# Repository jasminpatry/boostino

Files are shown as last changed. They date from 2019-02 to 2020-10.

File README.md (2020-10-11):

# BooSTIno
A Teensy 3.6-based logger and gauge for my 2014 Subaru STI.

Photo of current version:

BooSTIno (https://ibb.co/G0bdSqY)

Short [YouTube video](https://www.youtube.com/watch?v=nscQxxUsuL8) of older version, without faceplate or wideband support:

YouTube (https://www.youtube.com/watch?v=nscQxxUsuL8)

See [this thread on NASIOC](https://forums.nasioc.com/forums/showthread.php?t=2896098) for more info.

# Compilation

This project is built as an Arduino sketch. I used Arduino 1.8.8, but later versions will likely work too. You will also need the Teensyduino add-on
(https://www.pjrc.com/teensy/td_download.html), and the following libraries:

* My fork of ILI9341_t3: https://github.com/jasminpatry/ILI9341_t3
* My fork of Adafruit_GFX: https://github.com/jasminpatry/Adafruit-GFX-Library
* font_Exo-BoldItalic: https://github.com/FrankBoesing/fonts/tree/master/ofl/exo

# Hardware

This project was built using the following hardware:

* [Teensy 3.6](https://www.pjrc.com/store/teensy36.html)
* MC33660 K-line serial interface chip, SOP-8 package ([datasheet](https://www.nxp.com/docs/en/data-sheet/MC33660.pdf)); I purchased mine from [eBay](https://www.ebay.com/itm/10PCS-MC33660-MC33660EF-SOP-8/292559702234)
* Custom PCB fabricated using the files in the [KiCad/boostino.gerber](KiCad/boostino.gerber) directory (I used [BasicPCB](https://www.basicpcb.com/)'s ValueSpec option, which in 2020 cost me about $30 for 3 boards).
* [HiLetgo ILI9341 2.8" SPI TFT LCD Display Touch Panel 240X320 with PCB 5V/3.3V STM32](https://www.amazon.com/gp/product/B073R7BH1B/)
* [OBD-2 cable](https://www.amazon.com/gp/product/B01ETRINYO/) &mdash; the switch and DB9 connector in the linked cable aren't necessary (I snipped them off), but the DB9 connector was useful when prototyping.
* [Innovate Motorsports (3877) LC-2 Digital Wideband Lambda Controller Kit with Bosch LSU 4.9 O2 Sensor](https://www.amazon.com/Innovate-Motorsports-Digital-Wideband-Controller/dp/B00FFTAJPC/) (optional; only necessary for AFR display and logging)
* [Molex Micro-Fit 3.0 plug](https://www.amazon.com/gp/product/B078Q798L9/) for connecting to the LC-2 serial output (optional; only necessary for AFR display and logging)
* [Elcoho 10 Pieces Plastic Waterproof Boxes Junction Case Compatible with Electronic Project 3.94 × 2.36 × 0.98 Inches, Black](https://www.amazon.com/gp/product/B07G8S6XLV/)
* For the faceplate, I had [faceplate.eps](faceplate.eps) laser-cut by https://www.ponoko.com/ using:
    * Acrylic - Two Color - Brushed Silver on Black
    * 0.059 inches thick
    * P1 - 7.126 inches long x 7.126 inches wide
* Miscellaneous cables, headers, resistors, capacitors, diodes, wires, screws & nuts, etc.

# Tactrix Version

A previous version of this project used the [Tactrix OpenPort 2.0](https://www.tactrix.com/index.php?product_id=17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) to communicate with the ECU. That version is available in the [Tactrix](../../tree/Tactrix/) branch.

# Donate

If this project proves useful to you, please consider making a donation!



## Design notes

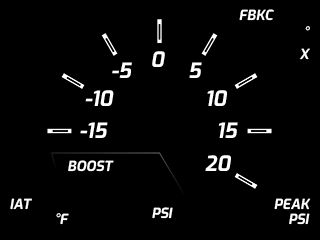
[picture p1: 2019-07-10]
gaugeFg.png

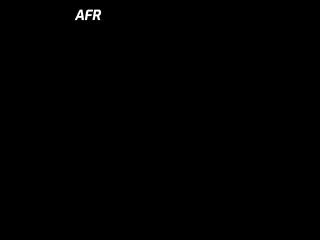
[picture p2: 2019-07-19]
labelAfr.png

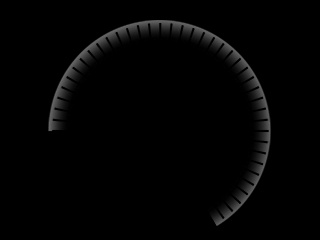
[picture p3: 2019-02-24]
gaugeBg.png

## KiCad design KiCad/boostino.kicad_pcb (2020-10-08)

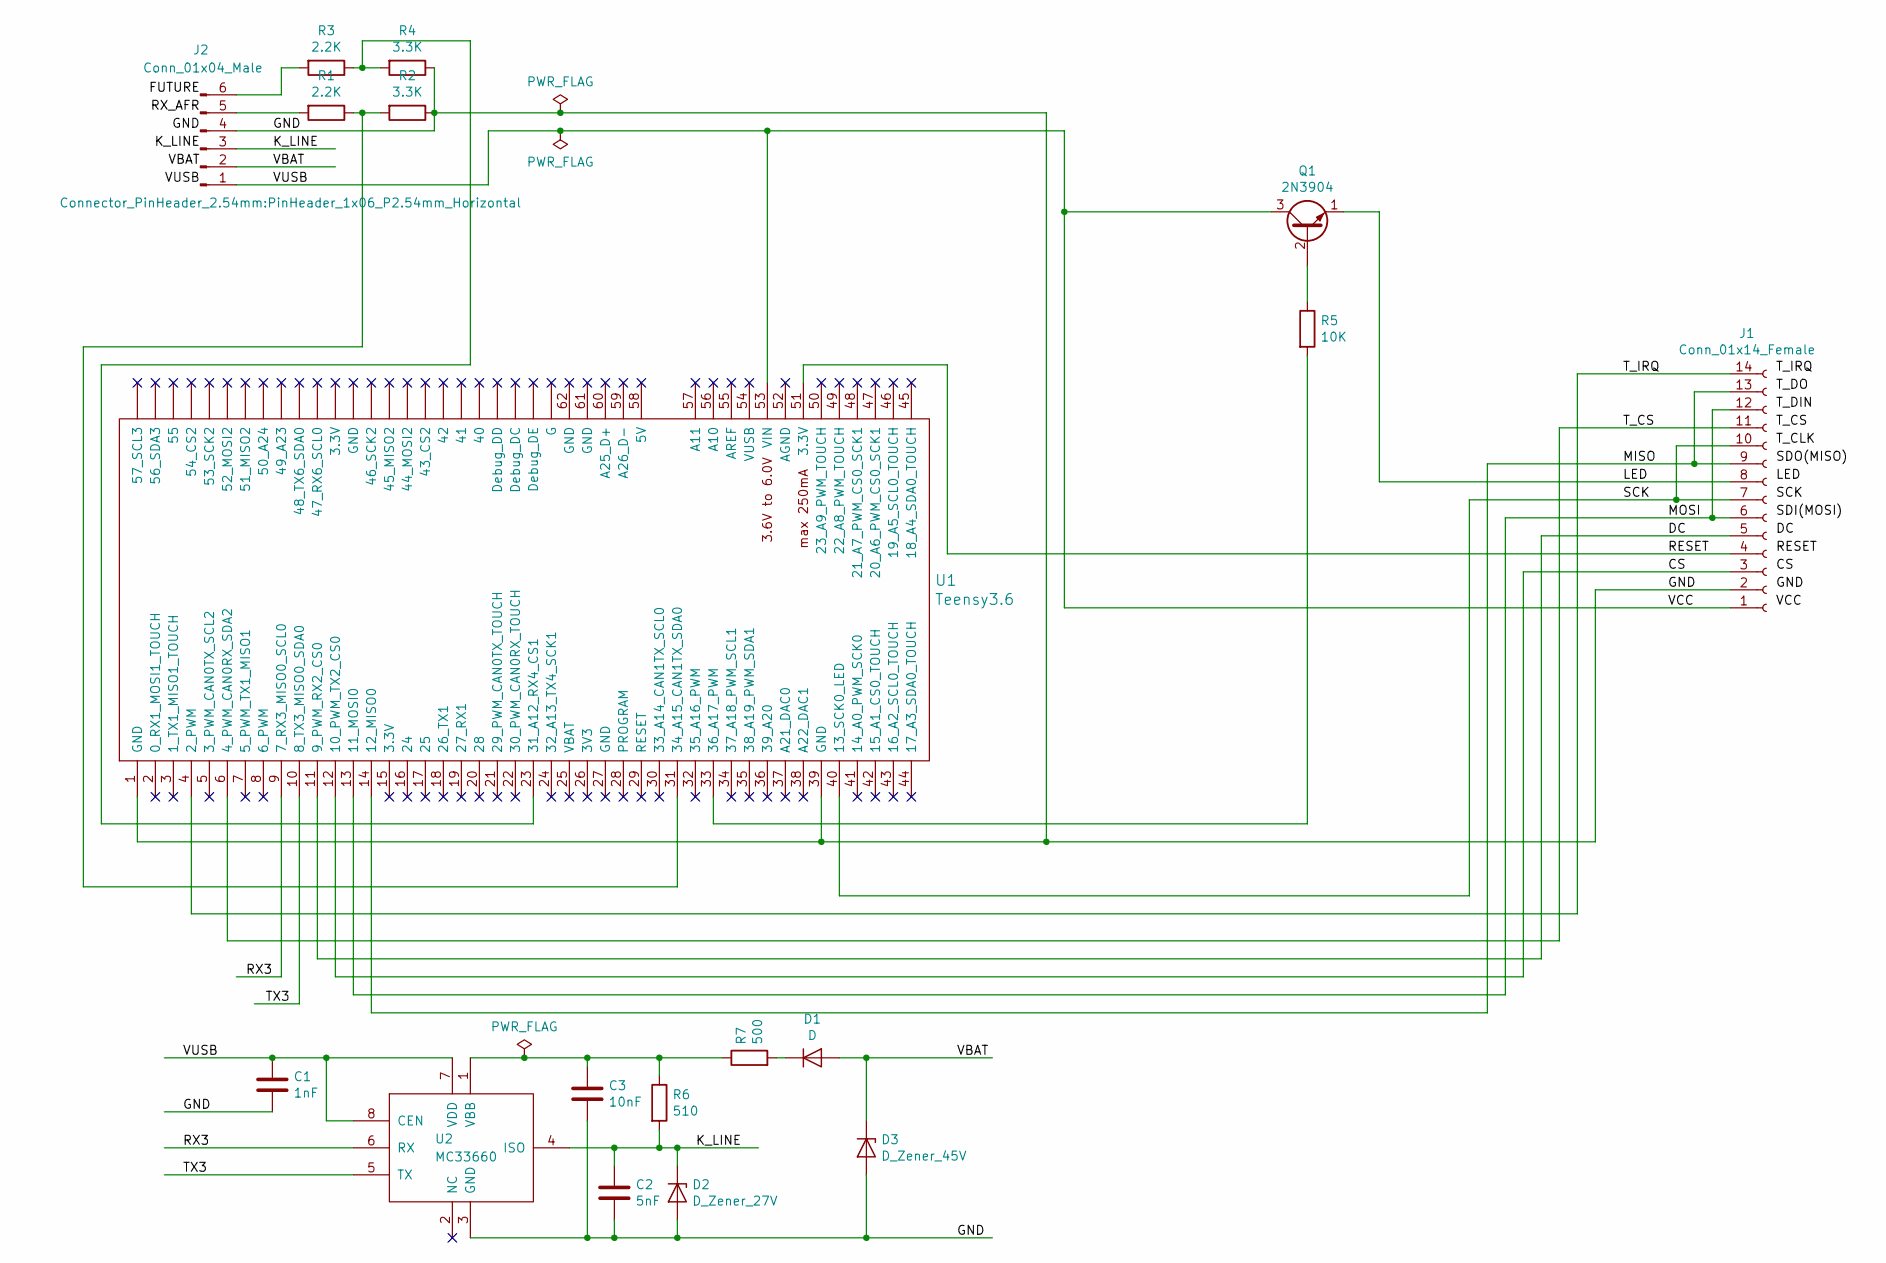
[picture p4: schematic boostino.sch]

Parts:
C1: 1nF; C_1206_3216Metric_Pad1.42x1.75mm_HandSolder
C2: 5nF; C_1206_3216Metric_Pad1.42x1.75mm_HandSolder
C3: 10nF; C_1206_3216Metric_Pad1.42x1.75mm_HandSolder
D1: D; D_A-405_P10.16mm_Horizontal
D2: D_Zener_27V; D_MiniMELF_Handsoldering
D3: D_Zener_45V; D_MiniMELF_Handsoldering
J1: Conn_01x14_Female; PinSocket_1x14_P2.54mm_Vertical
J2: Conn_01x04_Male; PinHeader_1x06_P2.54mm_Horizontal
Q1: 2N3904; TO-92_HandSolder
R1, R3: 2.2K; R_0805_2012Metric_Pad1.15x1.40mm_HandSolder
R2, R4: 3.3K; R_0805_2012Metric_Pad1.15x1.40mm_HandSolder
R5: 10K; R_0805_2012Metric_Pad1.15x1.40mm_HandSolder
R6: 510; R_0805_2012Metric_Pad1.15x1.40mm_HandSolder
R7: 500; R_0805_2012Metric_Pad1.15x1.40mm_HandSolder
U1: Teensy3.6; Teensy35_36
U2: MC33660; SOIC-8_3.9x4.9mm_P1.27mm

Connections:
/CS: J1.3, U1.12 (10_PWM_TX2_CS0)
/DC: J1.5, U1.11 (9_PWM_RX2_CS0)
/GND: C1.1, C2.1, C3.1, D2.2 (A), D3.2 (A), J1.2, J2.4, R2.1, R4.1, U1.1 (GND), U1.39 (GND), U2.3 (GND)
/K_LINE: C2.2, D2.1 (K), J2.3, R6.2, U2.4 (ISO)
/LED: J1.8, Q1.1 (E)
/MISO: J1.9, J1.13, U1.14 (12_MISO0)
/MOSI: J1.6, J1.12, U1.13 (11_MOSI0)
/RESET: J1.4, U1.51 (3.3V)
/RX3: U1.9 (7_RX3_MISO0_SCL0), U2.6 (RX)
/SCK: J1.7, J1.10, U1.40 (13_SCK0_LED)
/TX3: U1.10 (8_TX3_MISO0_SDA0), U2.5 (TX)
/T_CS: J1.11, U1.6 (4_PWM_CAN0RX_SDA2)
/T_IRQ: J1.14, U1.4 (2_PWM)
/VBAT: D1.2 (A), D3.1 (K), J2.2
/VCC: C1.2, J1.1, J2.1, Q1.3 (C), U1.53 (VIN), U2.7 (VDD), U2.8 (CEN)
unnamed: C3.2, R6.1, R7.1, U2.1 (VBB)
unnamed: D1.1 (K), R7.2
unnamed: J2.5, R1.2
unnamed: J2.6, R3.2
unnamed: Q1.2 (B), R5.1
unnamed: R1.1, R2.2, U1.31 (34_A15_CAN1TX_SDA0)
unnamed: R3.1, R4.2, U1.23 (31_A12_RX4_CS1)
unnamed: R5.2, U1.33 (36_A17_PWM)

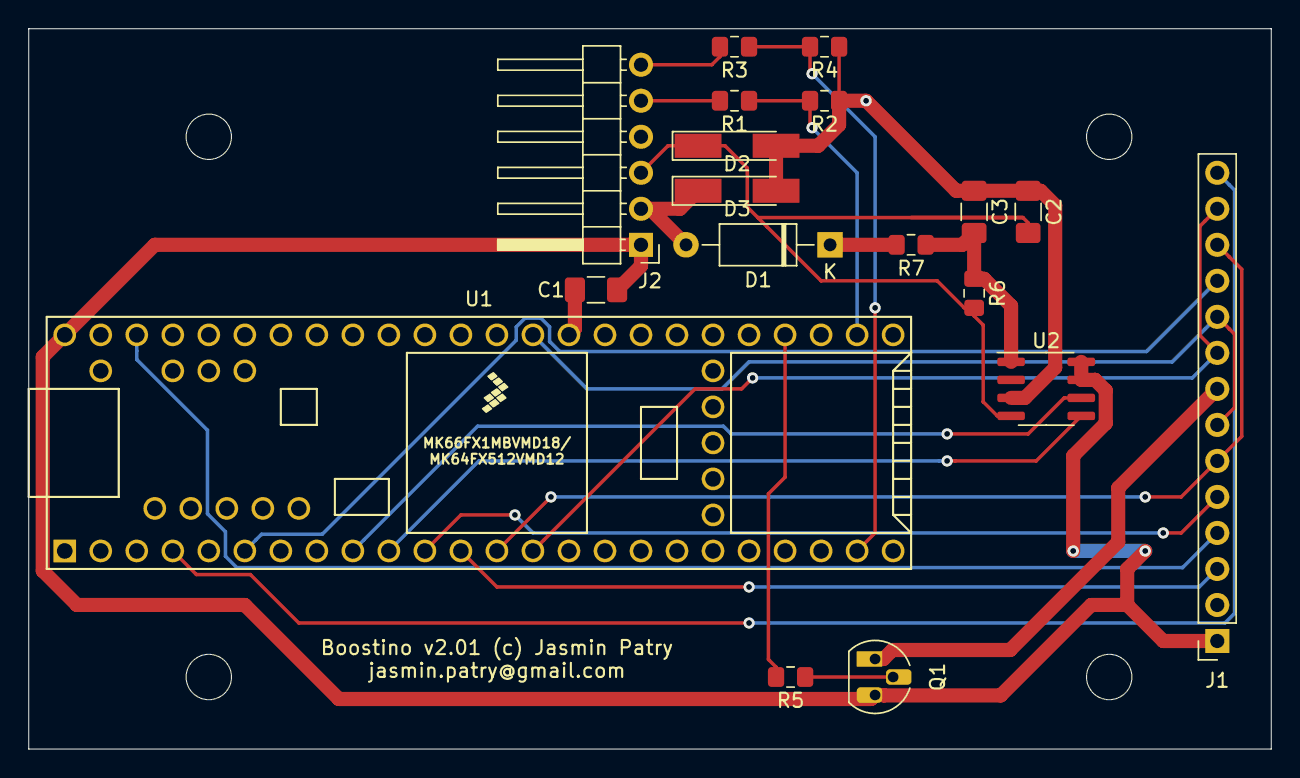
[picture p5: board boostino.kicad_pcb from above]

Board: 2 copper layers, 87.6 x 50.8 mm, 18 parts (0 on the bottom side), 23 nets.

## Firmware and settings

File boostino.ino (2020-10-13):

// Boostino -- A Teensy 3.6 SSM logger and gauge.
// Copyright (c) 2019, 2020 Jasmin Patry
//
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
#include <Adafruit_GFX.h>
#include <EEPROM.h>
#include <font_Exo-BoldItalic.h>
#include <ILI9341_t3.h>
#include <SD.h>
#include <XPT2046_Touchscreen.h>

#include "gaugeBg.h"
#include "gaugeFg.h"
#include "labelMph.h"
#include "labelAfr.h"



// Set to 1 to enable verbose logging.

#define DEBUG 0

static const bool s_fTraceComms = false;
static const bool s_fTraceTouch = false;

// Set to 1 to test without being plugged into the vehicle

#define TEST_OFFLINE 0



// Useful macros, typedefs, etc.

#define CASSERT(f) static_assert(f, #f)

template <typename T, int N>
constexpr int DIM(T (&aT)[N])
{
	(void)aT;
	return N;
}

typedef uint32_t	u32;
typedef int32_t		s32;
typedef uint16_t	u16;
typedef int16_t		s16;
typedef uint8_t		u8;
typedef int8_t		s8;

CASSERT(sizeof(int) == 4);		// Teensy 3.6 is 32-bit
CASSERT(sizeof(void *) == 4);	//	...

static const float s_gPi = 3.14159265f;

#define KLINE Serial3



// Available ECU parameters

enum PARAM
{
	PARAM_FbkcDeg,
	PARAM_FlkcDeg,
	PARAM_AtmPres,
	PARAM_ManifAbsPres,
	PARAM_BoostPsi,		// NOTE (jpatry) Calculated from PARAM_ManifAbsPres and PARAM_AtmPres
	PARAM_Iam,
	PARAM_CoolantTempF,	// BB (jpatry) Currently unused
	PARAM_Rpm,
	PARAM_Maf,
	PARAM_LoadGPerRev,	// NOTE (jpatry) Calculated from PARAM_Rpm and PARAM_Maf
	PARAM_IatF,
	PARAM_ThrottlePct,
	PARAM_SpeedMph,
	PARAM_IpwMs,
	PARAM_IdcPct,		// NOTE (jpatry) Calculated from PARAM_Rpm and PARAM_IpwMs
	PARAM_Afr1,
	PARAM_WidebandAfr,	// Read from analog input
	PARAM_TargetAfr,
	PARAM_MafVoltage,
	PARAM_LightSwitch,	// BB (jpatry) Always 1 unless parking brake is up, so not useful.

	PARAM_Max,
	PARAM_Min = 0,
	PARAM_Nil
};

PARAM & operator++(PARAM & param)
{
	param = PARAM(param + 1);
	return param;
}

static const char * s_mpParamPChz[] =
{
	"Feedback Knock Correction (4-byte)* (degrees)",	// PARAM_FbkcDeg
	"Fine Learning Knock Correction (degrees)",			// PARAM_FlkcDeg
	"Atmospheric Pressure (psi)",						// PARAM_AtmPres
	"Manifold Absolute Pressure (psi)",					// PARAM_ManifAbsPres
	"Manifold Relative Pressure (psi)",					// PARAM_BoostPsi
	"IAM (multiplier)",									// PARAM_Iam
	"Coolant Temperature (F)",							// PARAM_CoolantTempF
	"Engine Speed (rpm)",								// PARAM_Rpm
	"Mass Airflow (g/s)",								// PARAM_Maf
	"Engine Load (Calculated) (g/rev)",					// PARAM_LoadGPerRev
	"Intake Air Temperature (F)",						// PARAM_IatF
	"Throttle Opening Angle (%)",						// PARAM_ThrottlePct
	"Vehicle Speed (mph)",								// PARAM_SpeedMph
	"Fuel Injector #1 Pulse Width",						// PARAM_IpwMs
	"Injector Duty Cycle",								// PARAM_IdcPct
	"A/F Sensor #1",									// PARAM_Afr1
	"Wideband A/F Sensor",								// PARAM_WidebandAfr
	"Final Fueling Base (2-byte)* (estimated AFR)",		// PARAM_TargetAfr
	"Mass Airflow Sensor Voltage (V)",					// PARAM_MafVoltage
	"Light Switch",										// PARAM_LightSwitch
};
CASSERT(DIM(s_mpParamPChz) == PARAM_Max);

static const u8 s_cBSsmAddr = 3;
static const u32 s_mpParamABAddr[] =
{
	0xff81fc,		// PARAM_FbkcDeg
	0x000199,		// PARAM_FlkcDeg
	0x000023,		// PARAM_AtmPres
	0x00000D,		// PARAM_ManifAbsPres
	0x000000,		// PARAM_BoostPsi
	0x0000f9,		// PARAM_Iam
	0x000008,		// PARAM_CoolantTempF
	0x00000e,		// PARAM_Rpm
	0x000013,		// PARAM_Maf
	0x000000,		// PARAM_LoadGPerRev
	0x000012,		// PARAM_IatF
	0x000015,		// PARAM_ThrottlePct
	0x000010,		// PARAM_SpeedMph
	0x000020,		// PARAM_IpwMs
	0x000000,		// PARAM_IdcPct
	0x000046,		// PARAM_Afr1
	0x000000,		// PARAM_WidebandAfr
	0xff688a,		// PARAM_TargetAfr
	0x00001d,		// PARAM_MafVoltage
	0x000064,		// PARAM_LightSwitch
};
CASSERT(DIM(s_mpParamABAddr) == PARAM_Max);

static const u8 s_mpParamCB[] =
{
	 4,		// PARAM_FbkcDeg
	 1,		// PARAM_FlkcDeg
	 1,		// PARAM_AtmPres
	 1,		// PARAM_ManifAbsPres
	 0,		// PARAM_BoostPsi
	 1,		// PARAM_Iam
	 1,		// PARAM_CoolantTempF
	 2,		// PARAM_Rpm
	 2,		// PARAM_Maf
	 0,		// PARAM_LoadGPerRev
	 1,		// PARAM_IatF
	 1,		// PARAM_ThrottlePct
	 1,		// PARAM_SpeedMph
	 1,		// PARAM_IpwMs
	 0,		// PARAM_IdcPct
	 1,		// PARAM_Afr1
	 0,		// PARAM_WidebandAfr
	 2,		// PARAM_TargetAfr
	 1,		// PARAM_MafVoltage
	 1,		// PARAM_LightSwitch
};
CASSERT(DIM(s_mpParamCB) == PARAM_Max);

// BB (jpatry) Learning Table value data, for future:
// { 0xff31d4, 4, "A/F Learning #1 A (Stored)*" }, // float, x*100, %
// { 0xff31dc, 4, "A/F Learning #1 B (Stored)*" }, // float, x*100, %
// { 0xff31e4, 4, "A/F Learning #1 C (Stored)*" }, // float, x*100, %
// { 0xff31ec, 4, "A/F Learning #1 D (Stored)*" }, // float, x*100, %
// { 0x0000d1, 1, "A/F Learning #3" }, // u8, (x-128)*100/128, %
// { 0x000023, 1, "Atmospheric Pressure" }, //u8,  x*37/255, psi
// { 0x00001c, 1, "Battery Voltage" }, // u8, x*8/100, V
// { 0x000008, 1, "Coolant Temperature" }, // u8, 32+9*(x-40)/5, F
// { 0xff8298, 4, "Fine Learning Knock Correction (4-byte)*" }, // float, x, degrees
// { 0xff329c, 4, "IAM (4-byte)*" }, // float, x, multiplier
// { 0x000012, 1, "Intake Air Temperature" }, // u8, 32+9*(x-40)/5, F
// { 0x0cce3c, 4, "A/F Learning #1 Airflow Ranges", 3 }, // float, x, g/s
// { 0x0d3dd8, 4 ,"Fine Correction Columns (Load)", 4 }, // float, x, g/rev
// { 0x0d3dbc, 4 ,"Fine Correction Rows (RPM)", 6 }, // float, x, RPM
// { 0xff32b0, 4 ,"Fine Correction Row 1 (degrees)", 5, 4 /*stride*/ }, // float, x, RPM // NOTE (jpatry) Address is IAM (4-byte) + 4
// { 0xff32d8, 4 ,"Fine Correction Row 2 (degrees)", 5, 4 /*stride*/ }, // float, x, RPM
// { 0xff3300, 4 ,"Fine Correction Row 3 (degrees)", 5, 4 /*stride*/ }, // float, x, RPM
// { 0xff3328, 4 ,"Fine Correction Row 4 (degrees)", 5, 4 /*stride*/ }, // float, x, RPM
// { 0xff3350, 4 ,"Fine Correction Row 5 (degrees)", 5, 4 /*stride*/ }, // float, x, RPM
// { 0xff3378, 4 ,"Fine Correction Row 6 (degrees)", 5, 4 /*stride*/ }, // float, x, RPM
// { 0xff33a0, 4 ,"Fine Correction Row 7 (degrees)", 5, 4 /*stride*/ }, // float, x, RPM



// ECU Parameters to Poll

static const PARAM s_aParamPoll[] =
{
	PARAM_FbkcDeg,		// 4 B
	PARAM_Rpm,			// 2 B
	PARAM_ManifAbsPres,	// 1 B
	PARAM_AtmPres,		// 1 B
	PARAM_Maf,			// 2 B
	PARAM_FlkcDeg,		// 1 B
	PARAM_Iam,			// 1 B
	PARAM_IatF,			// 1 B
	PARAM_ThrottlePct,	// 1 B
	PARAM_SpeedMph,		// 1 B
	PARAM_TargetAfr,	// 2 B
};
static const u8 s_cParamPoll = DIM(s_aParamPoll);



// ECU Parameters to Log

static const PARAM s_aParamLog[] =
{
	PARAM_LoadGPerRev,
	PARAM_Rpm,
	PARAM_Maf,
	PARAM_FbkcDeg,
	PARAM_FlkcDeg,
	PARAM_BoostPsi,
	PARAM_IatF,
	PARAM_ThrottlePct,
	PARAM_Iam,
	PARAM_WidebandAfr,
	PARAM_TargetAfr,
};
static const u8 s_cParamLog = DIM(s_aParamLog);



// Debugging support

inline void Trace(bool f, const char * pChz)
{
#if DEBUG
	if (f)
		Serial.print(pChz);
#endif // DEBUG
}

inline void Trace(bool f, u8 b, int mode = DEC)
{
#if DEBUG
	if (f)
		Serial.print(b, mode);
#endif // DEBUG
}

#if DEBUG
void Trace(bool f, char ch)
{
	if (!f)
		return;

	if (isprint(ch))
	{
		Serial.print(ch);
	}
	else
	{
		switch (ch)
		{
		case '\r':
			Serial.print("\\r");
			break;

		case '\n':
			Serial.print("\\n");
			break;

		case '\0':
			Serial.print("\\0");
			break;

		default:
			Serial.print("\\x");
			Serial.print(u8(ch), HEX);
			break;
		}
	}
}
#else // !DEBUG
inline void Trace(bool f, char ch)
{
}
#endif // !DEBUG

inline void Trace(bool f, u16 uN, int mode = DEC)
{
#if DEBUG
	if (f)
		Serial.print(uN, mode);
#endif // DEBUG
}

inline void Trace(bool f, s16 n, int mode = DEC)
{
#if DEBUG
	if (f)
		Serial.print(n, mode);
#endif // DEBUG
}

inline void Trace(bool f, u32 uN, int mode = DEC)
{
#if DEBUG
	if (f)
		Serial.print(uN, mode);
#endif // DEBUG
}

inline void Trace(bool f, int n, int mode = DEC)
{
#if DEBUG
	if (f)
		Serial.print(n, mode);
#endif // DEBUG
}

inline void Trace(bool f, float g, int cDigit = 2)
{
#if DEBUG
	if (f)
		Serial.print(g, cDigit);
#endif // DEBUG
}

#if DEBUG
void TraceHex(bool f, u8 b)
{
	if (!f)
		return;

	if (b < 0x10)
		Trace(true, '0');

	Trace(true, b, HEX);
}
#else // !DEBUG
inline void TraceHex(bool f, u8 b)
{
}
#endif // !DEBUG

#if DEBUG
void TraceHex(bool f, const u8 * aB, u16 cB)
{
	if (!f || cB == 0)
		return;

	int iB = 0;
	for (;;)
	{
		u8 b = aB[iB];
		TraceHex(true, b);

		++iB;
		if (iB >= cB)
			break;

		Trace(true, ' ');

		if (!(iB & 0xf))
			Trace(true, "\n");
		else if (!(iB & 0x3))
			Trace(true, "| ");
	}
	Trace(true, "\n");
}
#else // !DEBUG
inline void TraceHex(bool f, const u8 * aB, u16 cB)
{
}
#endif // !DEBUG



// BB (jpatry) Assigning __LINE__ to nAssertLine is necessary to get rid of warning about 'large integer implicitly
//	truncated to unsigned type'.

#define ASSERT(f)								\
	do											\
	{											\
		if (!(f))								\
		{										\
			Trace(true, "Assert failed (");		\
			Trace(true, __FILE__);				\
			Trace(true, ":");					\
			u32 nAssertLine = __LINE__;			\
			Trace(true, nAssertLine);			\
			Trace(true, "): ");					\
			Trace(true, #f);					\
			Trace(true, "\n");					\
		}										\
	} while(0)



// Subaru Select Monitor (SSM) protocol description: http://www.romraider.com/RomRaider/SsmProtocol
// Max SSM packet size is ~250 bytes

static const u8 s_cBSsmMax = 250;



// SSM Source/Destination IDs (ISO9141)

enum SSMID : u8
{
	SSMID_Ecu	  = 0x10,
	SSMID_TcuDccd = 0x18,
	SSMID_Tool	  = 0xf0,
};



// SSM Command/Response IDs

enum SSMCMD : u8
{
	SSMCMD_BlockReadRequest		= 0xa0,
	SSMCMD_AddressReadRequest	= 0xa8,
	SSMCMD_AddressReadResponse	= 0xe8,
	SSMCMD_WriteBlockRequest	= 0xb0,
	SSMCMD_AddressWriteRequest	= 0xb8,
	SSMCMD_EcuInitRequest		= 0xbf,
	SSMCMD_EcuInitResponse		= 0xff,
};



u8 BSsmChecksum(const u8 * aB, u16 cB)
{
	u8 bSum = 0;
	for (int iB = 0; iB < cB; ++iB)
		bSum += aB[iB];

	return bSum;
}



static const u8 s_bSsmHdr = 0x80;



// SSM Packet

struct SSsm	// tag = ssm
{
	u8		m_bHdr;				// 0x80
	SSMID	m_bDst;				// Destination
	SSMID	m_bSrc;				// Source
	u8		m_cB;				// Data + checksum size
	SSMCMD	m_bCmd;				// Command/response byte
	u8		m_aB[0];			// Data (including checksum as last byte)

	u8			CBPacket() const
					{ return sizeof(*this) + m_cB; }

	u8			CBData() const
					{ return m_cB - 1; }

	const u8 *	PBData() const
					{ return m_aB; }

	u8 *		PBChecksum()
					{ return &m_aB[CBData()]; }

	u8			BChecksum() const
					{ return m_aB[CBData()]; }

	u8			BComputeChecksum() const;
	bool		FVerifyChecksum() const;
};

u8 SSsm::BComputeChecksum() const
{
	const u8 * aB = (const u8 *)this;
	int cB = CBPacket() - 1;
	return BSsmChecksum(aB, cB);
}

bool SSsm::FVerifyChecksum() const
{
	u8 bChecksum = BComputeChecksum();
	if (bChecksum == BChecksum())
	{
		return true;
	}
	else
	{
		Trace(true, "SSM checksum error\n");
		return false;
	}
}



// Log entry

struct SLogEntry	// tag = logent
{
	u32		m_msTimestamp;
	float	m_mpIParamLogGValue[s_cParamLog];
};

// Number of entries in log history

static const int s_cEntryLogHistory = 32;

// Circular buffer of data to log, with capacity s_cEntryLogHistory

class CLogHistory
{
public:
	u8					CEntry() const
							{ return m_iaGWrite - m_iaGRead; }
	bool				FIsEmpty() const
							{ return m_iaGRead == m_iaGWrite; }
	bool				FIsFull() const
							{ return CEntry() == s_cEntryLogHistory; }
	const SLogEntry &	LogentRead();
	void				WriteLogEntry(const SLogEntry & logent);

protected:
	// Implementation based on https://www.snellman.net/blog/archive/2016-12-13-ring-buffers/

	CASSERT(s_cEntryLogHistory <= u8(~0));
	CASSERT((s_cEntryLogHistory & (s_cEntryLogHistory - 1)) == 0);

	u8				IMask(u8 i)
						{ return i & (s_cEntryLogHistory - 1); }

	SLogEntry		m_aLogent[s_cEntryLogHistory];
	u8				m_iaGRead;						// unmasked read index
	u8				m_iaGWrite;						// unmasked write index
};

const SLogEntry & CLogHistory::LogentRead()
{
	ASSERT(!FIsEmpty());
	return m_aLogent[IMask(m_iaGRead++)];
}

void CLogHistory::WriteLogEntry(const SLogEntry & logent)
{
	// Allow writing to full buffer by discarding oldest entry

	if (FIsFull())
		(void) LogentRead();

	m_aLogent[IMask(m_iaGWrite++)] = logent;
}

CLogHistory g_loghist;



// Wideband analog input

static const int s_cBitAnalog = 13;
static const float s_rAnalog = 1.0f / ((1 << s_cBitAnalog) - 1);



static const u32 s_dMsTimeoutDefault = 500;



// Connection State

enum CNXNS
{
	CNXNS_Idle,
	CNXNS_Polling,
};

class CConnectionMgr	// tag = cnxnmgr
{
public:
					CConnectionMgr()
					: m_cnxns(CNXNS_Idle),
					  m_rcvs(RCVS_Waiting),
					  m_aBRecv(),
					  m_cBRecv(0),
					  m_msRecv(0),
					  m_msReadResponse(0),
					  m_cBParamPoll(0),
					  m_mpParamGValue()
						{ ; }

					~CConnectionMgr()
						{ ; }

	void			Disconnect();
	bool			FTryStartPolling();
	bool			FTryUpdatePolling();
	CNXNS			Cnxns() const
						{ return m_cnxns; }
	float			GParam(PARAM param) const;
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
void loop()
{
	g_clock.Update();

	// Flip buffers

	swap(g_pCnvs, g_pCnvsPrev);

	// Draw splash screen for 5 seconds, or until we connect

	static const u32 s_msSplashMax = 5000;

	u32 msCur = millis();

	if (msCur <= s_msSplashMax)
		DrawSplashScreen();

	// Detect touchscreen events

	bool fTouch = false;
	if (!g_ts.bufferEmpty())
	{
		TS_Point posTouch = g_ts.getPoint();
		static const int s_zTouchMin = 500;
		if (posTouch.z >= s_zTouchMin)
		{
			fTouch = true;

			g_xTouch = map(posTouch.x, s_xTsMin, s_xTsMax, 0, s_dXScreen);
			g_yTouch = map(posTouch.y, s_yTsMin, s_yTsMax, 0, s_dYScreen);

			Trace(s_fTraceTouch, "Touch point: ");
			Trace(s_fTraceTouch, g_xTouch);
			Trace(s_fTraceTouch, " ");
			Trace(s_fTraceTouch, g_yTouch);
			Trace(s_fTraceTouch, " pressure ");
			Trace(s_fTraceTouch, posTouch.z);
			Trace(s_fTraceTouch, "\n");

			g_fTouch = true;
		}
	}

	bool fTouchRelease = false;
	if (!fTouch && g_fTouch)
	{
		g_fTouch = false;
		fTouchRelease = true;

		Trace(true, "Touch release: ");
		Trace(true, g_xTouch);
		Trace(true, " ");
		Trace(true, g_yTouch);
		Trace(true, "\n");
	}

	// Check for screen brightness inputs

	if (fTouchRelease && abs(g_xTouch - 160) <= 30)
	{
		if (abs(g_yTouch - 30) <= 30)
		{
			if (g_nvram.m_bright != BRIGHT_High)
			{
				g_scrnfdr.SetBrightnessTarget(BRIGHT_High);
				g_nvram.m_bright = BRIGHT_High;
				g_nvram.Write();
			}
		}
		else if (abs(g_yTouch - 210) <= 30)
		{
			if (g_nvram.m_bright != BRIGHT_Low)
			{
				g_scrnfdr.SetBrightnessTarget(BRIGHT_Low);
				g_nvram.m_bright = BRIGHT_Low;
				g_nvram.Write();
			}
		}
	}

	if (g_cnxnmgr.Cnxns() == CNXNS_Idle)
	{
		if (msCur > s_msSplashMax)
			DisplayStatus("Polling ECU...");

		if (!g_cnxnmgr.FTryStartPolling())
		{
			g_cnxnmgr.Disconnect();
			delay(s_dMsTimeoutDefault);
		}
	}

	if (g_cnxnmgr.Cnxns() == CNXNS_Polling)
	{
		if (g_cnxnmgr.FTryUpdatePolling())
		{
			// Update data, handle touch events, draw gauge and log if necessary

			g_pCnvs->fillScreen(s_iColorBlack);

			static float s_gBoostMax = -1000.0f;

			// Check for max boost reset event

			if (fTouchRelease && g_xTouch >= 245 && g_yTouch >= 195)
				s_gBoostMax = -1000.0f;

			float gBoost = g_cnxnmgr.GParam(PARAM_BoostPsi);
			s_gBoostMax = max(gBoost, s_gBoostMax);

			static float s_degFbkcAnyMin = 0.0f;
			static float s_degFbkcHighLoadMin = 0.0f;
			static float s_degFbkcPrev = 0.0f;
			static u32 s_msFbkcEventLast = 0;
			static int s_cFbkcEvent = 0;
			float degFbkc = g_cnxnmgr.GParam(PARAM_FbkcDeg);
			float gLoad = g_cnxnmgr.GParam(PARAM_LoadGPerRev);

			// Check for min FBKC reset event

			if (fTouchRelease && g_xTouch >= 240 && g_yTouch <= 55)
			{
				s_degFbkcHighLoadMin = 0.0f;
				s_cFbkcEvent = 0;
			}

			if (fTouchRelease && g_xTouch <= 100 && g_yTouch <= 40)
			{
				g_nvram.m_fDisplayMph = !g_nvram.m_fDisplayMph;
			}

			// Check if we have a new FBKC event (ignore small, low-load events for display, but still log them)

			static const float s_gLoadHighThreshold = 1.25f;
			static const float s_degFbkcLowLoadThreshold = -3.0f;
			if (degFbkc < s_degFbkcPrev && (gLoad > s_gLoadHighThreshold || degFbkc < s_degFbkcLowLoadThreshold))
			{
				++s_cFbkcEvent;
				s_degFbkcHighLoadMin = min(degFbkc, s_degFbkcHighLoadMin);
			}

			s_degFbkcPrev = degFbkc;
			s_degFbkcAnyMin = min(degFbkc, s_degFbkcAnyMin);

			if (degFbkc < 0.0f)
				s_msFbkcEventLast = msCur;

			static float s_degFlkcMin = 1000.0f;
			static u32 s_msFlkcEventLast = 0;
			float degFlkc = g_cnxnmgr.GParam(PARAM_FlkcDeg);
			s_degFlkcMin = min(degFlkc, s_degFlkcMin);
			if (degFlkc < 0.0f)
				s_msFlkcEventLast = msCur;

			static float s_uIamMin = 1.0f;

			static const float s_sRadiusIamCircle = 32;
			static const int s_xBoostCenter = 160;
			static const int s_yBoostCenter = 131;

			// Check for min IAM reset event

			if (fTouchRelease)
			{
				int dXTouch = g_xTouch - s_xBoostCenter;
				int dYTouch = g_yTouch - s_yBoostCenter;
				if (dXTouch * dXTouch + dYTouch * dYTouch < s_sRadiusIamCircle * s_sRadiusIamCircle)
					s_uIamMin = 1.0f;
			}

			float uIam = g_cnxnmgr.GParam(PARAM_Iam);
			s_uIamMin = min(uIam, s_uIamMin);

			// Check if doing a WOT pull

			static const int s_cWotThreshold = 20;
			CASSERT(s_cWotThreshold < s_cEntryLogHistory);

			static int s_cWot = 0;
			float gThrottlePct = g_cnxnmgr.GParam(PARAM_ThrottlePct);
			if (gThrottlePct > 95.0f)
				++s_cWot;
			else
				s_cWot = 0;

			float gSpeedMph = g_cnxnmgr.GParam(PARAM_SpeedMph);

			// Write to log if WOT for long enough, or if min IAM < 1 or a knock event happened recently

			static const bool s_fLogAlways = false;

			bool fWriteToLog = (s_nLogSuffix &&
								gSpeedMph >= 5.0f &&
								(s_fLogAlways ||
								 s_cWot >= s_cWotThreshold ||
								 s_uIamMin < 1.0f ||
								 (s_degFbkcAnyMin < 0.0f && msCur - s_msFbkcEventLast < s_msLogAfterEvent) ||
								 (s_degFlkcMin < 0.0f && msCur - s_msFlkcEventLast < s_msLogAfterEvent)));

			g_pCnvs->setT3Font(&Exo_28_Bold_Italic);

			// Boost gauge
			// NOTE (jpatry) Angles measured CCW from +X axis (3 o'clock).
			//	Boost of 0 = 12 o'clock; -15 = 9 o'clock; +15 = 3 o'clock.

			float radBoost = (6.0f * gBoost + 90.0f) * s_gPi / 180.0f;
			float radBoostMax = (6.0f * s_gBoostMax + 90.0f) * s_gPi / 180.0f;
			float gSinBoost = sinf(radBoost);
			float gCosBoost = cosf(radBoost);
			float gCotanBoost = gCosBoost / gSinBoost;
			static const int s_sNeedle = 113;

			{
				// Draw boost gauge background, with portion behind needle in red

				const u8 * pB = &g_aBGaugeBg[0];
				if (radBoost < s_gPi)
				{
					for (int iY = g_aNBbGaugeBg[1]; iY < g_aNBbGaugeBg[3]; ++iY)
					{
						int diY = iY - s_yBoostCenter;
						int iXRedMac;
						if (diY >= 0)
							iXRedMac = -1;
						else
							iXRedMac = min(g_aNBbGaugeBg[2], roundf(float(diY) * gCotanBoost + s_xBoostCenter));

						u8 * aBRow = g_pCnvs->getBuffer() + iY * s_dXScreen;
						int iX;
						for (iX = g_aNBbGaugeBg[0]; iX < iXRedMac; ++iX)
						{
							u8 b = *pB++;
							aBRow[iX] = 0x20 | (b >> 2);
						}
						for (; iX < g_aNBbGaugeBg[2]; ++iX)
						{
							u8 b = *pB++;
							aBRow[iX] = b >> 3;
						}
					}
				}
				else
				{
					for (int iY = g_aNBbGaugeBg[1]; iY < g_aNBbGaugeBg[3]; ++iY)
					{
						int diY = iY - s_yBoostCenter;
						int iXRedMic;
						if (diY <= 0)
							iXRedMic = g_aNBbGaugeBg[0];
						else
							iXRedMic = min(g_aNBbGaugeBg[2], roundf(float(diY) * gCotanBoost + s_xBoostCenter));

						u8 * aBRow = g_pCnvs->getBuffer() + iY * s_dXScreen;
						int iX;
						for (iX = g_aNBbGaugeBg[0]; iX < iXRedMic; ++iX)
						{
							u8 b = *pB++;
							aBRow[iX] = b >> 3;
						}
						for (; iX < g_aNBbGaugeBg[2]; ++iX)
						{
							u8 b = *pB++;
							aBRow[iX] = 0x20 | (b >> 2);
						}
					}
				}
			}

			// Draw boost gauge foreground

			DrawAbIntoCanvas(&g_aBGaugeFg[0], g_aNBbGaugeFg);

			// Draw MPH/AFR label

			if (g_nvram.m_fDisplayMph)
				DrawAbIntoCanvas(&g_aBLabelMph[0], g_aNBbLabelMph);
			else
				DrawAbIntoCanvas(&g_aBLabelAfr[0], g_aNBbLabelAfr);

			char aChz[16];

			{
				// Draw boost value, aligning at decimal point

				int cCh = snprintf(aChz, DIM(aChz), "%.1f", fabsf(gBoost));
				char chDec = aChz[cCh - 1];
				aChz[cCh - 1] = '\0';

				g_pCnvs->setCursor(138 - g_pCnvs->strPixelLen(aChz), 175);
				aChz[cCh - 1] = chDec;
				g_pCnvs->print(aChz);

				if (gBoost < 0.0f)
				{
					g_pCnvs->setCursor(77, 175);
					g_pCnvs->write('-');
				}
			}

			if (g_nvram.m_fDisplayMph)
			{
				// Draw speed

				snprintf(aChz, DIM(aChz), "%d", int(roundf(gSpeedMph)));
				g_pCnvs->setCursor(66 - g_pCnvs->strPixelLen(aChz), 10);
				g_pCnvs->print(aChz);
			}
			else
			{
				// Draw AFR and align at decimal point

				float gAfr = g_cnxnmgr.GParam(PARAM_WidebandAfr);

				// Clamp at 19.9 because we don't have room for 2x.x

				gAfr = min(19.9f, gAfr);

				int cCh = snprintf(aChz, DIM(aChz), "%.1f", gAfr);

				char chDec = aChz[cCh - 1];
				aChz[cCh - 1] = '\0';

				g_pCnvs->setCursor(47 - g_pCnvs->strPixelLen(aChz), 10);
				aChz[cCh - 1] = chDec;

				g_pCnvs->print(aChz);
			}

			g_pCnvs->setT3Font(&Exo_16_Bold_Italic);

			{
				// Draw IAT

				float gIatF = g_cnxnmgr.GParam(PARAM_IatF);
				snprintf(aChz, DIM(aChz), "%d", int(roundf(gIatF)));
				g_pCnvs->setCursor(51 - g_pCnvs->strPixelLen(aChz), 214);
				g_pCnvs->print(aChz);
			}

			// Draw FBKC
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

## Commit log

2019-02-03 Initial commit (copy of Teensy USBHost_t36 SerialTest example).
2019-02-04 Initial Tactrix framework
2019-02-06 Add TraceHex
2019-02-10 Add throttle pct and convert some params to 1-byte versions.
2019-06-19 Filter out low-load, low-intensity knock
2019-06-19 Always fully update one scanline to recover in case of display corruption.
2019-07-26 Calibrated AFR and added filter to display
2019-12-23 Update wideband calibration
2020-01-24 Remove voltage divider
    Innovate LC-2 now configured to output 0-3 V instead of 0-5.
2020-01-27 Use serial input for wideband AFR instead of analog.
    I was having problems maintaining accurate readings over the analog output of the Innovate Motorsports LC-2 wideband, so
    this change switches to using the serial output of the LC-2. The LC-2 outputs 0-5V RS-232 serial, so I'm using a voltage
    divider (2.2K & 3.3K) to step down to 0-3V, and using RXINV since TTL and RS-232 serial are inverted.
    [boostino.ino]
2020-01-30 Serial wideband display fixes and improvements.
    [boostino.ino]
2020-02-02 Add light switch detection and brightness adjustment
2020-02-18 Add touch controls for screen brightness.
    Remove LightSwitch detection since it always returns 1 when parking brake isn't on.
2020-09-06 Avoid clipping boost; save display brightness in EEPROM.
    [boostino.ino]
2020-09-27 Add KiCad and Gerber files for PCB
    [boostino-B_Cu.gbr, boostino-B_Mask.gbr, boostino-Edge_Cuts.gbr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]
2020-09-27 Add KiCad gitignore
2020-09-29 Updated PCB for MC33660. Still need to regenerate Gerber files.
    [boostino.kicad_pcb, boostino.sch]
2020-10-02 Generate Gerber files, bump PCB version to 2.0.
    [boostino-B_Cu.gbr, boostino-B_Mask.gbr, boostino-Edge_Cuts.gbr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]
2020-10-08 Label diode in schematic
    [boostino.sch]
2020-10-08 Move K-Line to Serial3, and move touch CS pin from 8 to 6.
2020-10-08 Update PCB to use Serial3 for K-Line
    [boostino-B_Cu.gbr, boostino-B_Mask.gbr, boostino-Edge_Cuts.gbr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]
2020-10-11 Update component values.
    Alternate values in brackets where applicable.
    [boostino.sch]
2020-10-13 Fix touch CS pin number
    [boostino.ino]

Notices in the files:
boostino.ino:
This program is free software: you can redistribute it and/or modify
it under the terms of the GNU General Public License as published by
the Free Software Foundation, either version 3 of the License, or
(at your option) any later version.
